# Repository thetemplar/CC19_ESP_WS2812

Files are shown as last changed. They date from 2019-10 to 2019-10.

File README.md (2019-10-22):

# Coding Challenge 2019 - Trinket!

Beschreibungen und Handouts der CC19 der EFS!
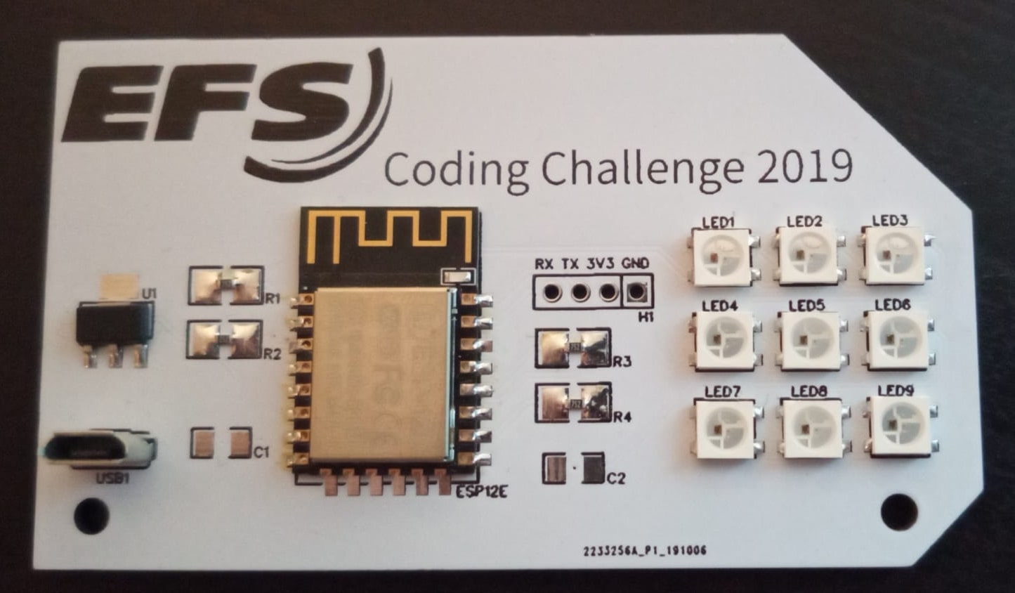
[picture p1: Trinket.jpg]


## Was ist drauf?
- ESP8266-12E
- AMS1117-3.3
- Micro-USB-Buchse (nur zur Stromversorgung)
- 9x WS2812
- Widerstände zum Betrieb des ESP8266
- optional: Kondensatoren
- optional: UART Header

## Was ist geflasht?
Eine per Arduino-IDE geschriebene Software, welche ein kleines LED-Lichtspiel anzeigt und parallel dazu die ersten 10 Minuten nach dem Booten ein WLAN-AP auf macht, um sich per OTA flashen zu lassen.

## Wie flashe ich selber?
1) Arduino-IDE laden
2) ESP8266 Bib laden (https://github.com/esp8266/Arduino)
3) OTA Funktion durchlesen (https://arduino-esp8266.readthedocs.io/en/latest/ota_updates/readme.html#arduino-ide)  
> ggf ist es nicht notwendig extra Python zu installieren
4) Sich in das WLAN des ESP8266 verbinden (heißt CC19_ESP8266_<hex-chip-id\>)
5) Bei Board "NodeMCU 1.0 .." auswählen, bei Port die Netzwerkschnittstelle (siehe Settings.png in diesem Repo)
6) Flashen
**ACHTUNG!** Neue Software muss auch OTA unterstützen, am besten die FW dieses Repos als Basis nutzen!

## [ERROR]: No response from device
Unter Windows muss die Firewall ggf ausgeschaltet werden (obwohl sie vorher fragt ob man die Firewall-Regel hinzufügen will)

## I fcked up... 
ESP8266 "gebrickt" oder OTA geht nicht? Alternativ per UART (also nach einem FTDI-Adapter wie CP210x oder FT232RL) die Platine über die Header anschließen. Damit der Bootloader in den Flashmodus geht, muss **VOR** Powerup der GPIO-0 auf Masse gezogen werden. Dies geht am besten in dem das linke Pad des oberen rechten Widerstands auf Masse gezogen wird! Für alles weitere gibt es viele viele Tutorials im Internet.  Zum Beispiel [hier](https://alselectro.wordpress.com/2016/11/07/esp8266-upload-code-from-arduino-ide-no-arduino-board-required/) oder
[hier](https://www.instructables.com/id/ESP-12F-ESP8266-Module-Minimal-Breadboard-for-Flas/).

## Details zu den Robots
siehe "robot.pdf"

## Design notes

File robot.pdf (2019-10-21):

Category | Hardware | Part Number | Data Sheet & Info | Available

Sensors
| Camera module | Raspberry Pi - camera module v2.1 | https://www.raspberrypi.org/documentation/hardware/camera/
| Ultrasonic sensor | Grove - Ultrasonic Ranger | http://wiki.seeedstudio.com/Grove-Ultrasonic_Ranger/
| IMU | Adafruit - BNO055 | https://learn.adafruit.com/adafruit-bno055-absolute-orientation-sensor

Board
| Jetson Nano | NVIDIA Jetson Nano - P3448 | https://developer.nvidia.com/embedded/jetson-nano-developer-kit

Actuator
| Gearbox Motor | DC Gearbox Motor - "TT Motor" - 200RPM - 3 to 6VDC | https://www.adafruit.com/product/3777

Other Electronics
| I2C Motor Driver | Grove - I2C Motor Driver | http://wiki.seeedstudio.com/Grove-I2C_Motor_Driver_V1.3/
| I2C Hub | Grove - I2C Hub | http://wiki.seeedstudio.com/Grove-I2C_Hub/
| Step up converter | JOY-IT - XL6019 Step-UP Converter | http://anleitung.joy-it.net/wp-content/uploads/2018/09/SBC-XL6019-Datenblatt_27-09-18.pdf

Display
| OLED Display | Grove OLED display 1.12" | http://wiki.seeedstudio.com/Grove-OLED_Display_1.12inch/
| LED Ring | NeoPixel Ring - 12 x 5050 RGB LED | https://www.adafruit.com/product/1643

Accessories
Micro SD card with Jetson Nano Image | Intenso 64 GB Micro SD | -
Micro SD card adapter | - | -
| WLAN USB Adapter | ASUS - USB-N10 NANO | https://www.asus.com/Networking/USBN10_NANO/HelpDesk_Download/
Castor wheel mounted on base | - | -
Power Bank | Intenso Powerbank S10000 | -

Cables
| Jumper - Female to Female | - | -
| Jumper - Male to Female | - | -
| Micro USB - USB cable | - | -
| Camera extension cable | - | -
| I2C 4 Pin Cable | - | -

3D printed
| Jetson Nano Case | - | -
| Glass holder | - | -
| Camera mount | - | -
| Ultrasonic sensor mount | - | -

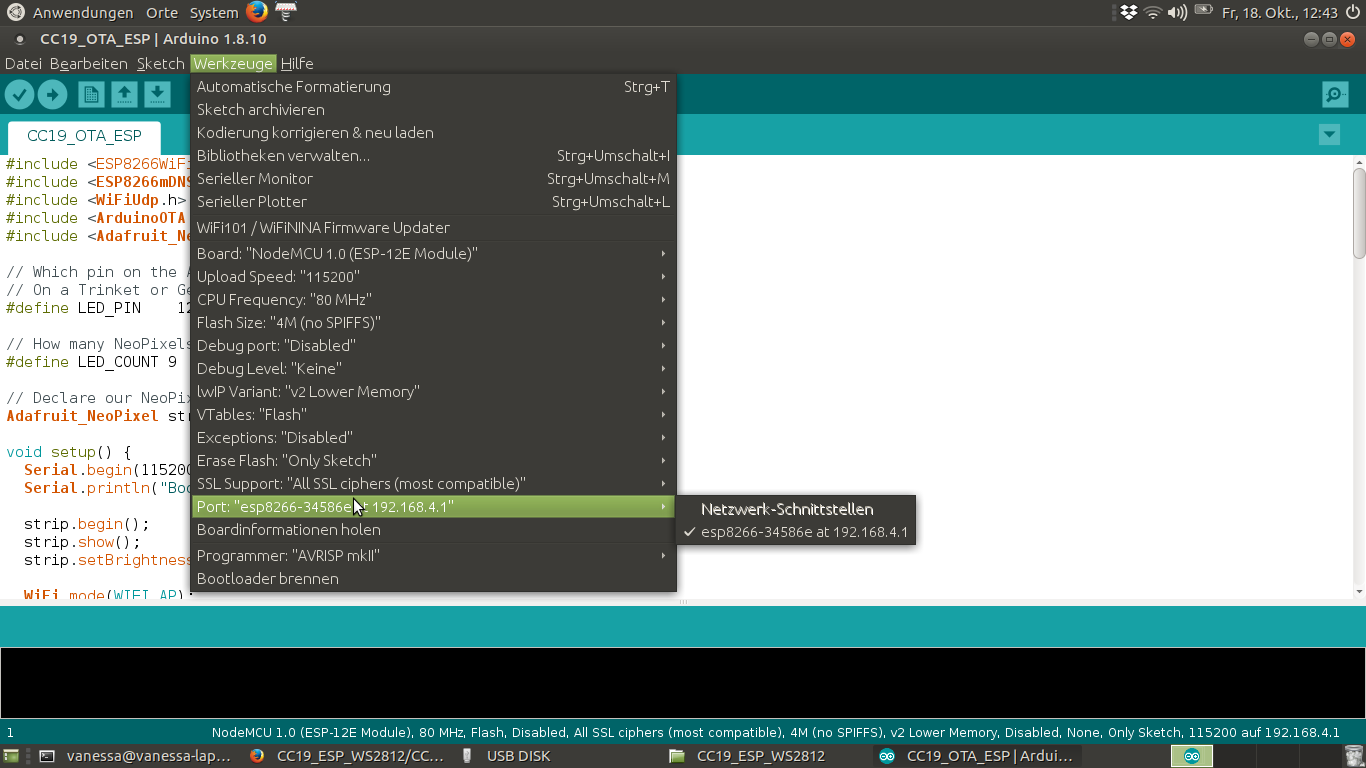
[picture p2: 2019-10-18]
Settings.png

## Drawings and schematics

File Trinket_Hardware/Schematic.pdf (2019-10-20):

# GND 15 IO15 16 IO2 17 IO0 18 IO4 19 IO5 20 RXD 21 TXD 22

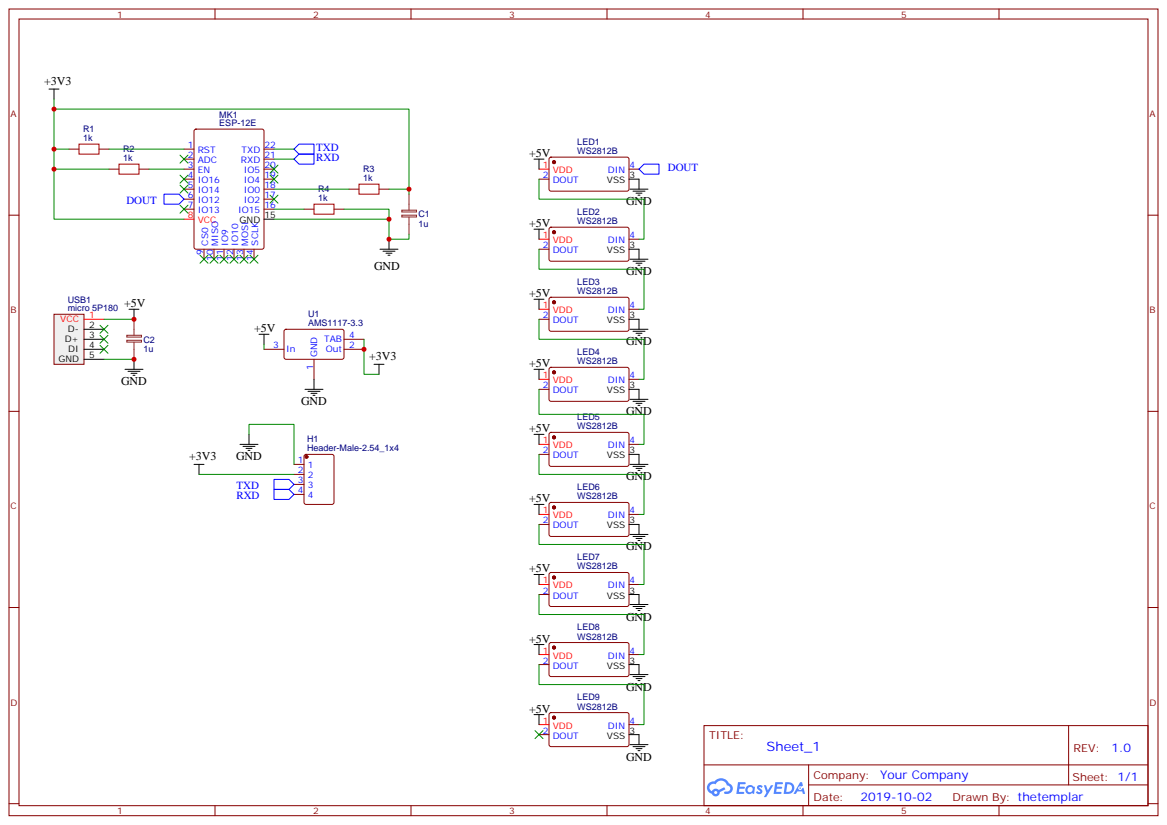
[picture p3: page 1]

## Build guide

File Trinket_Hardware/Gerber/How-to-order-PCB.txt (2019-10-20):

How to Order PCB

Please refer to:
https://docs.easyeda.com/en/PCB/Order-PCB

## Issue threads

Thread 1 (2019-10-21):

GPIO0 und RST mit auf den Programming Header

haniham, 2019-10-21:
Bitte in zukünftigen Versionen am besten immer GPIO0 und RST mit auf den Programming Header legen

ala: https://www.youtube.com/watch?v=RUXA5IcSB7g

thetemplar, 2019-10-28:
Wird das nächste Mal brücksichtigt. Ursprünglich war gar kein Header geplant (nur OTA), daher das "unvollständige"-Pinlayout. :)

Closed 2019-10-28.

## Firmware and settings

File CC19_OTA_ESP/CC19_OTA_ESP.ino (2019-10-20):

#include <ESP8266WiFi.h>
#include <ESP8266mDNS.h>
#include <WiFiUdp.h>
#include <ArduinoOTA.h>
#include <Adafruit_NeoPixel.h>

// Which pin on the Arduino is connected to the NeoPixels?
// On a Trinket or Gemma we suggest changing this to 1:
#define LED_PIN    12

// How many NeoPixels are attached to the Arduino?
#define LED_COUNT 9

// Declare our NeoPixel strip object:
Adafruit_NeoPixel strip(LED_COUNT, LED_PIN, NEO_GRB + NEO_KHZ800);

void setup() {
  Serial.begin(115200);
  Serial.println("Booting");
    
  strip.begin();           // INITIALIZE NeoPixel strip object (REQUIRED)
  strip.show();            // Turn OFF all pixels ASAP
  strip.setBrightness(50); // Set BRIGHTNESS to about 1/5 (max = 255)
  
  WiFi.mode(WIFI_AP);
  long chipId = ESP.getChipId();
  
  Serial.println("Host: " + String(chipId, HEX));
  String host = "CC19_ESP8266_" + String(chipId, HEX);
  WiFi.softAP(host);

  String otaHostName = "CC19 OTA ESP8266_" + String(chipId, HEX);
  char otaHostNameChar[otaHostName.length()+1];
  otaHostName.toCharArray(otaHostNameChar, otaHostName.length());
  ArduinoOTA.setHostname(otaHostNameChar);
  ArduinoOTA.onStart([]() {
    String type;
    if (ArduinoOTA.getCommand() == U_FLASH) {
      type = "sketch";
    } else { // U_SPIFFS
      type = "filesystem";
    }

    // NOTE: if updating SPIFFS this would be the place to unmount SPIFFS using SPIFFS.end()
    Serial.println("Start updating " + type);
  });
  ArduinoOTA.onEnd([]() {
    Serial.println("\nEnd");
  });
  ArduinoOTA.onProgress([](unsigned int progress, unsigned int total) {
    Serial.printf("Progress: %u%%\r", (progress / (total / 100)));
  });
  ArduinoOTA.onError([](ota_error_t error) {  
    Serial.printf("Error[%u]: ", error);
    if (error == OTA_AUTH_ERROR) {
      Serial.println("Auth Failed");
    } else if (error == OTA_BEGIN_ERROR) {
      Serial.println("Begin Failed");
    } else if (error == OTA_CONNECT_ERROR) {
      Serial.println("Connect Failed");
    } else if (error == OTA_RECEIVE_ERROR) {
      Serial.println("Receive Failed");
    } else if (error == OTA_END_ERROR) {
      Serial.println("End Failed");
    }
  });
  ArduinoOTA.begin();
  Serial.println("Ready");
  Serial.print("IP address: ");
  Serial.println(WiFi.localIP());
}

void loop() {
  ArduinoOTA.handle();
  rainbow(10);
  if(millis() > 600000)
	WiFi.mode(WIFI_OFF);
}

// Fill strip pixels one after another with a color. Strip is NOT cleared
// first; anything there will be covered pixel by pixel. Pass in color
// (as a single 'packed' 32-bit value, which you can get by calling
// strip.Color(red, green, blue) as shown in the loop() function above),
// and a delay time (in milliseconds) between pixels.
void colorWipe(uint32_t color, int wait) {
  for(int i=0; i<strip.numPixels(); i++) { // For each pixel in strip...
    strip.setPixelColor(i, color);         //  Set pixel's color (in RAM)
    strip.show();                          //  Update strip to match
    delay(wait);                           //  Pause for a moment
  }
}

// Rainbow cycle along whole strip. Pass delay time (in ms) between frames.
void rainbow(int wait) {
  // Hue of first pixel runs 1 complete loops through the color wheel.
  // Color wheel has a range of 65536 but it's OK if we roll over, so
  // just count from 0 to 65536. Adding 256 to firstPixelHue each time
  // means we'll make 65536/256 = 1280 passes through this outer loop:
  for(long firstPixelHue = 0; firstPixelHue < 65536; firstPixelHue += 256) {
    for(int i=0; i<strip.numPixels(); i++) { // For each pixel in strip...
      // Offset pixel hue by an amount to make one full revolution of the
      // color wheel (range of 65536) along the length of the strip
      // (strip.numPixels() steps):
      int pixelHue = firstPixelHue + (i * 65536L / strip.numPixels());
      // strip.ColorHSV() can take 1 or 3 arguments: a hue (0 to 65535) or
      // optionally add saturation and value (brightness) (each 0 to 255).
      // Here we're using just the single-argument hue variant. The result
      // is passed through strip.gamma32() to provide 'truer' colors
      // before assigning to each pixel:
      strip.setPixelColor(i, strip.gamma32(strip.ColorHSV(pixelHue)));
      //do basic-software stuff (ESP8266) - normly its done at the end of each main-"loop"-cycle
      yield();
    }
    strip.show(); // Update strip with new contents
    delay(wait);  // Pause for a moment
  }
}

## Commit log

2019-10-20 Added Hardware
    [Gerber_BoardOutline.GKO, Gerber_BottomLayer.GBL, Gerber_BottomSilkLayer.GBO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]
2019-10-20 Fixed HW-Bug for future use (not on delivered trinkets)
    [Gerber_BoardOutline.GKO, Gerber_BottomLayer.GBL, Gerber_BottomSilkLayer.GBO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]
